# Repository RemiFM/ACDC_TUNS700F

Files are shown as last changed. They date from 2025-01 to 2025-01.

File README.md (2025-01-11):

# 700W 28V AC-DC Module
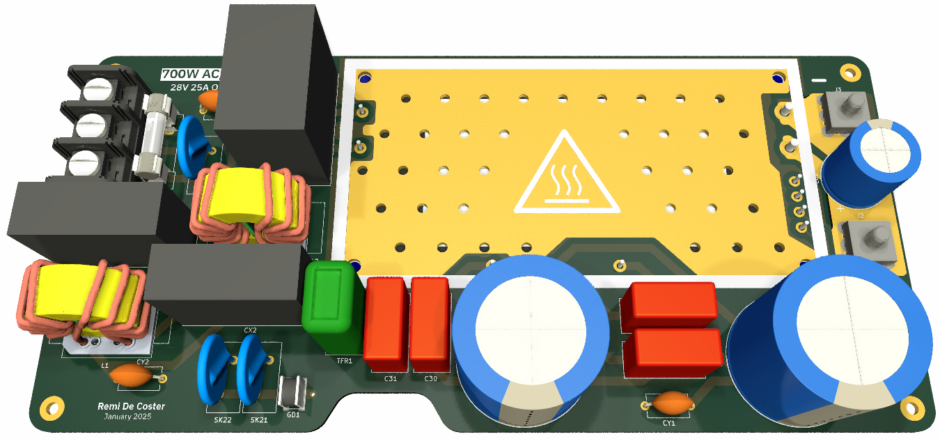
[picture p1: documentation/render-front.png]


PCB carrier board for the Cosel TUNS700F28 AC/DC converter with 28V 25A output. The board can also be used for the TUNS700F12 and TUNS700F48 modules by swapping certain components.
The board is desgined using KiCAD 8 and contains all line filtering and safety protections as recommended in the manufacturer design guide.

> [!CAUTION]
> The power converter operates at AC voltages of 230VAC and delivers up to 700W of power. Improper handling can result in serious injury, electric shock, or fire.

## Ordering Components
A [bill of materials (BOM)](BOM.csv) is available for download. The BOM contains Digi-Key part numbers, and is formatted in a way that can be uploaded to the Digi-Key website for effortless ordering.

## Assembly
For assembly, please make use of the provided [schematic](schematic.pdf), available in pdf format.

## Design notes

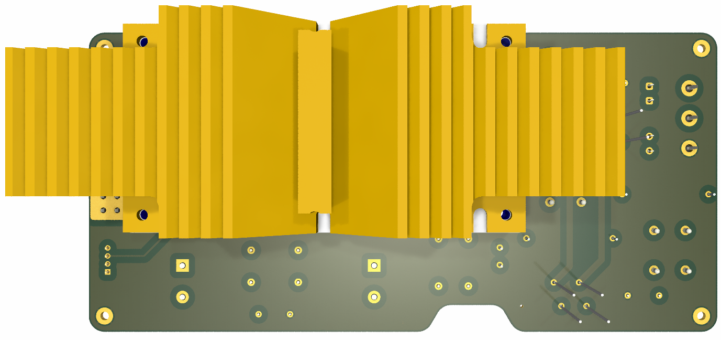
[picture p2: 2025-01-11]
documentation/render-back.png

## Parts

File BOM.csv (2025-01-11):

Reference | Value | Qty | Digi-Key
C11 | 3.3uF | 1 | P123489-ND
C20,C30 | 680nF | 2 | P14204-ND
C21,C31 | 2x680nF | 2 | P14204-ND
C40 | 10uF | 1 | 445-C3216X7R1H106K160AECT-ND
Cbc1,Cbc2 | 2x390uF | 2 | 493-7913-ND
Co1 | 1mF | 1 | 565-2007-ND
CX1,CX2 | 1.5uF | 2 | P15515-ND
CY1,CY2,CY3 | 2.2nF | 3 | 445-174537-ND
F1 | 15A | 1 | F3251-ND + 2 * F4225-ND
GD1 | GDT_2Pin | 1 | 2093-300-SM-RPLFCT-ND
HS1 | ATS1490-ND | 1 | ATS1490-ND
J1 | Screw_Terminal_01x03 | 1 | A98496-ND
J2 | +VO | 1 | 732-74651194RCT-ND
J3 | -VO | 1 | 732-74651194RCT-ND
J4 | Conn_01x04_Pin | 1
L1,L2 | 4.5mH | 2 | 553-3962-ND
R1,R2,R3,R4,R5,R6 | 68k | 6 | 311-68KERCT-ND
SK11,SK21,SK22 | 620V | 3 | 495-5945-ND
TFR1 | 10R 139°C | 1 | 285-1901-ND
U1 | TUNS700F28 | 1 | 1776-1798-ND

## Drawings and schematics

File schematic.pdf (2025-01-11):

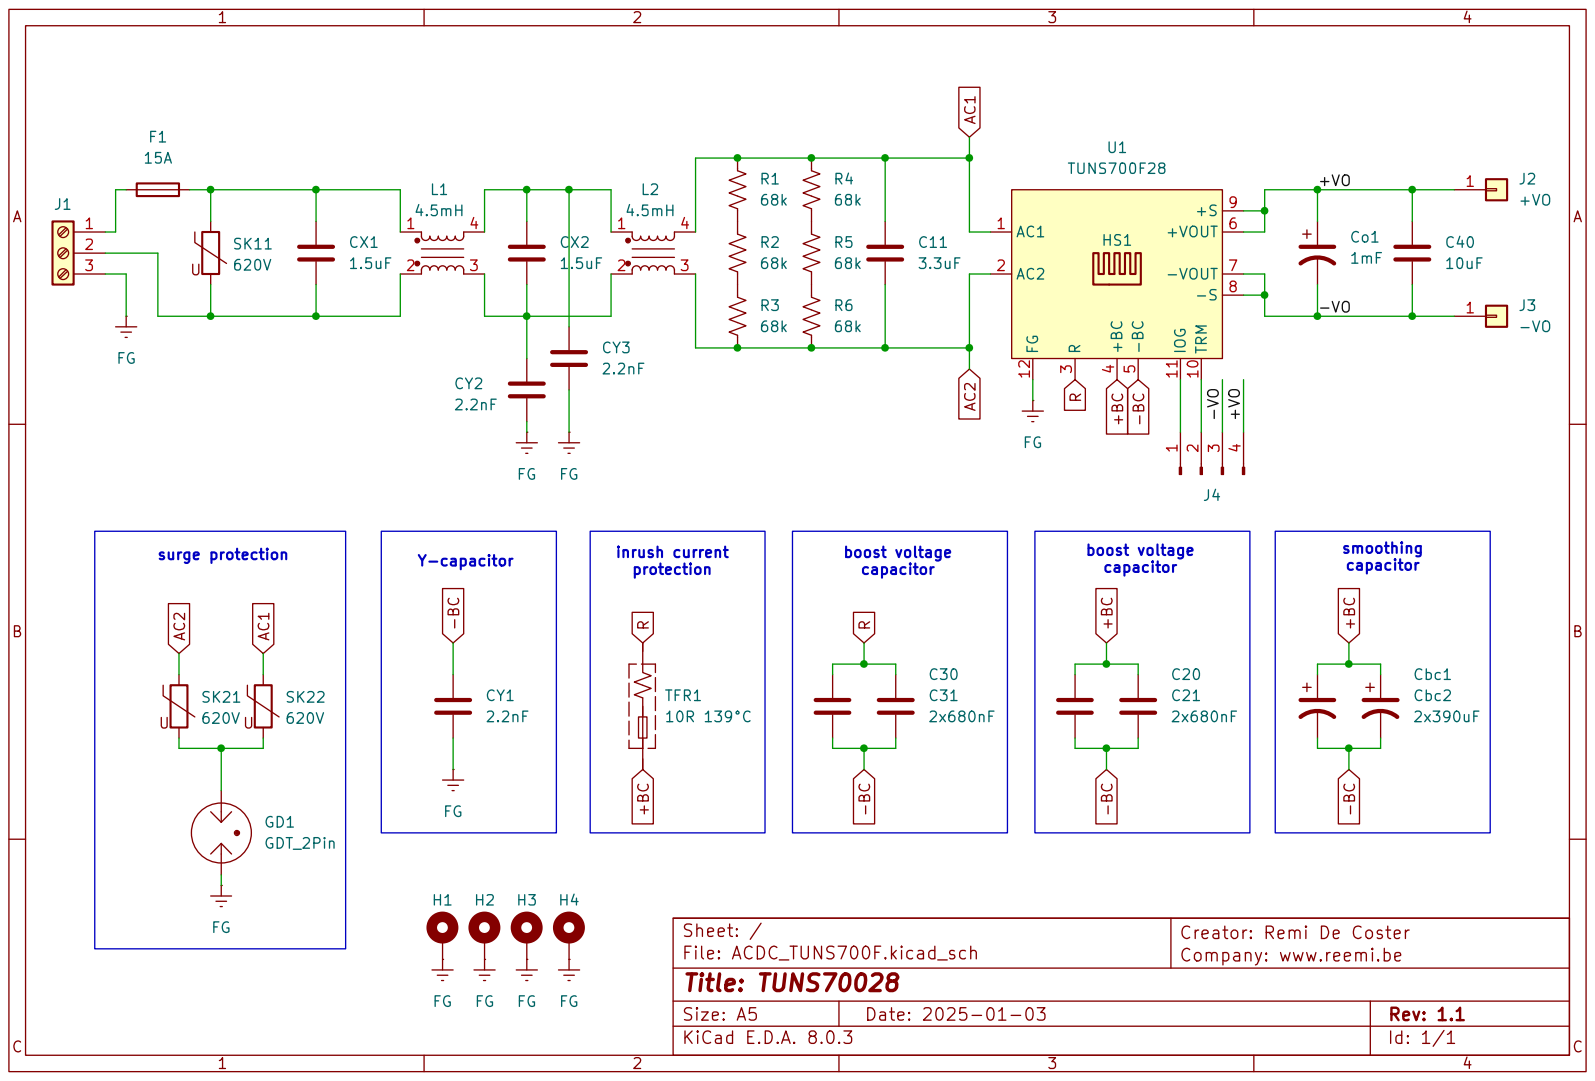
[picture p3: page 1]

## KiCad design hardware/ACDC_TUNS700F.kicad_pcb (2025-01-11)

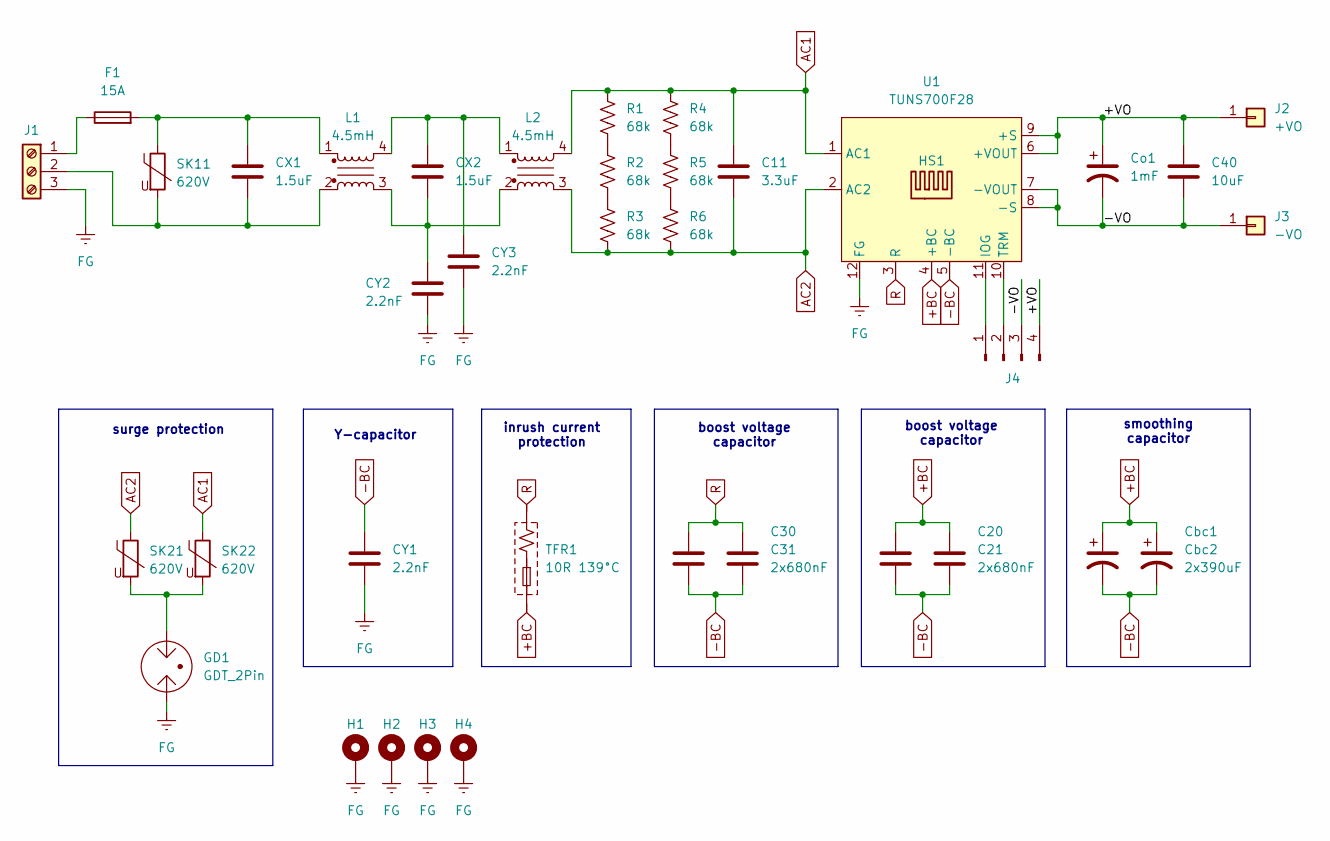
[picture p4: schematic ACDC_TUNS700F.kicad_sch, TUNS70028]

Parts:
C11: 3.3uF; CAP-ECQ-UAAF335K; Digi-Key P123489-ND
C20, C30: 680nF; C_Rect_L18.0mm_W8.0mm_P15.00mm_FKS3_FKP3; Digi-Key P14204-ND
C21, C31: 2x680nF; C_Rect_L18.0mm_W8.0mm_P15.00mm_FKS3_FKP3; Digi-Key P14204-ND
C40: 10uF; C_1206_3216Metric_Pad1.33x1.80mm_HandSolder; Digi-Key 445-C3216X7R1H106K160AECT-ND
CX1, CX2: 1.5uF; CAP-ECQ-UAAF155K; Digi-Key P15515-ND
CY1, CY2, CY3: 2.2nF; C_Disc_D9.0mm_W5.0mm_P10.00mm; Digi-Key 445-174537-ND
Cbc1, Cbc2: 2x390uF; CP_Radial_D30.0mm_P10.00mm_SnapIn; Digi-Key 493-7913-ND
Co1: 1mF; CP_Radial_D16.0mm_P7.50mm; Digi-Key 565-2007-ND
F1: 15A; Fuseholder_Clip-5x20mm_Littelfuse_100_Inline_P20.50x4.60mm_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; Digi-Key F3251-ND + 2 * F4225-ND
GD1: GDT_2Pin; GDT_2093-300-SM-RPLF; Digi-Key 2093-300-SM-RPLFCT-ND
H1, H2, H3, H4: MountingHole_Pad; MountingHole_2.7mm_M2.5_Pad
HS1: ATS1490-ND; Digi-Key ATS1490-ND
J1: Screw_Terminal_01x03; terminal_NC6-P108-03; Digi-Key A98496-ND
J2: +VO; Wuerth_REDCUBE-THR_WP-THRSH_74651194_THR; Digi-Key 732-74651194RCT-ND
J3: -VO; Wuerth_REDCUBE-THR_WP-THRSH_74651194_THR; Digi-Key 732-74651194RCT-ND
J4: Conn_01x04_Pin; PinHeader_1x04_P2.54mm_Vertical
L1, L2: 4.5mH; CMC_PH9455.405NL; Digi-Key 553-3962-ND
R1, R2, R3, R4, R5, R6: 68k; R_1206_3216Metric_Pad1.30x1.75mm_HandSolder; Digi-Key 311-68KERCT-ND
SK11, SK21, SK22: 620V; RV_Disc_D15,5mm_W7,1mm_P7,5mm; Digi-Key 495-5945-ND
TFR1: 10R 139°C; TFR_DFP10112; Digi-Key 285-1901-ND
U1: TUNS700F28; Digi-Key 1776-1798-ND

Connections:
+BC: C20.1, C21.1, Cbc1.1, Cbc2.1, TFR1.2, U1.4 (+BC)
-BC: C20.2, C21.2, C30.2, C31.2, CY1.1, Cbc1.2, Cbc2.2, U1.5 (-BC)
/+VO: C40.1, Co1.1, J2.1, J4.4, U1.6 (+VOUT), U1.9 (+S)
/-VO: C40.2, Co1.2, J3.1, J4.3, U1.7 (-VOUT), U1.8 (-S)
AC1: C11.1, L2.4, R1.1, R4.1, SK22.1, U1.1 (AC1)
AC2: C11.2, L2.3, R3.2, R6.2, SK21.1, U1.2 (AC2)
FG: CY1.2, CY2.2, CY3.2, GD1.1, H1.1, H2.1, H3.1, H4.1, J1.3, U1.12 (FG)
unnamed: CX1.1, F1.2, L1.1, SK11.1
unnamed: CX2.1, CY3.1, L1.4, L2.1
unnamed: CX2.2, CY2.1, L1.3, L2.2
unnamed: GD1.3, SK21.2, SK22.2
unnamed: F1.1, J1.1
unnamed: CX1.2, J1.2, L1.2, SK11.2
unnamed: J4.1, U1.11 (IOG)
unnamed: J4.2, U1.10 (TRM)
unnamed: R1.2, R2.1
unnamed: R2.2, R3.1
unnamed: R4.2, R5.1
unnamed: R5.2, R6.1
R: C30.1, C31.1, TFR1.1, U1.3 (R)

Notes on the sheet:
Y-capacitor
surge protection
boost voltage capacitor
smoothing capacitor
inrush current protection

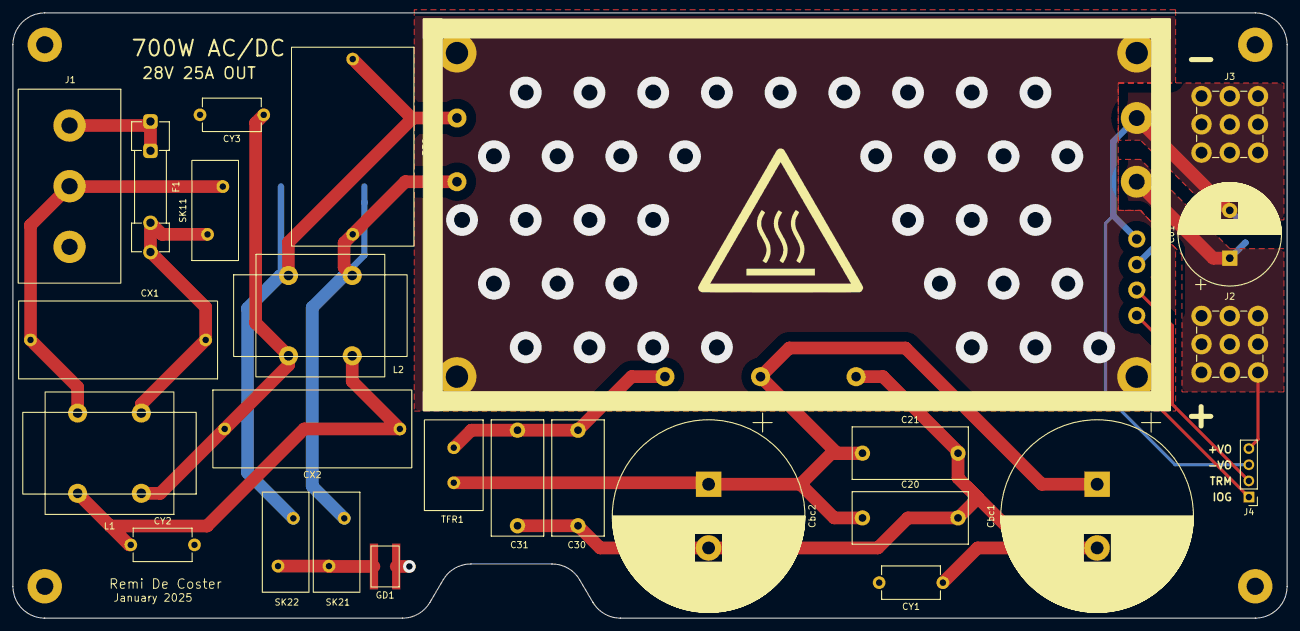
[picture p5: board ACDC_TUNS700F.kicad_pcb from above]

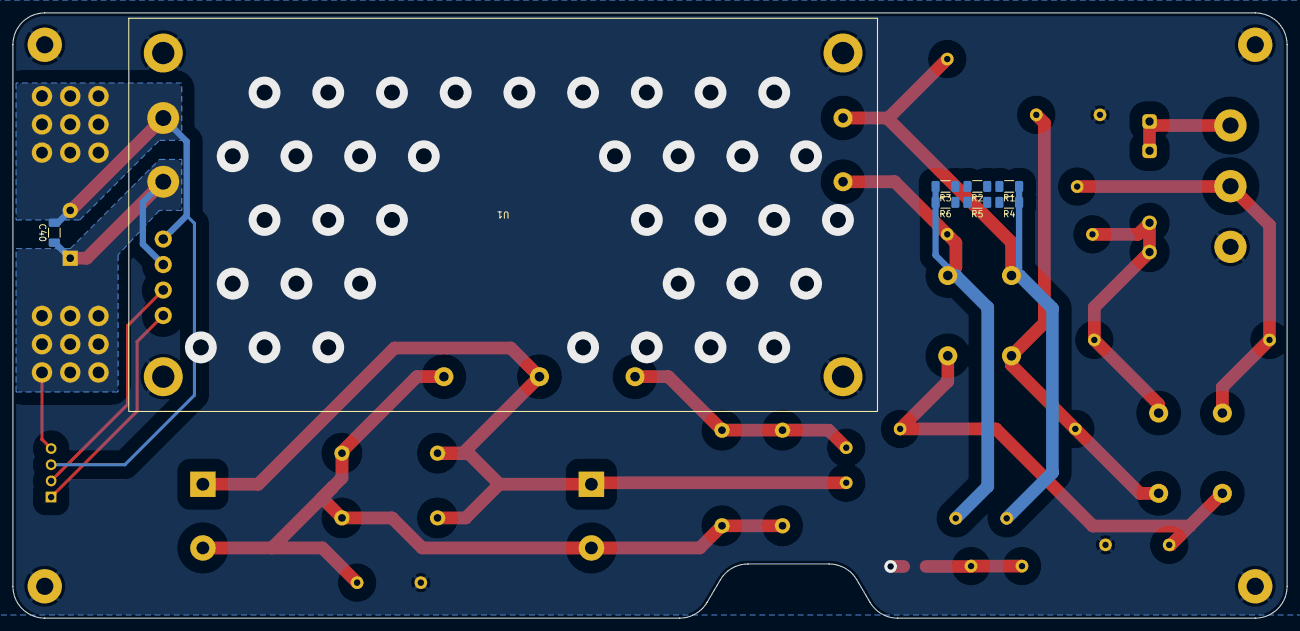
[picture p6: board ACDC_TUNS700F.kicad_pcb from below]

Board: 2 copper layers, 200.0 x 95.0 mm, 37 parts (8 on the bottom side), 20 nets.

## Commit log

2025-01-03 footprint creation
    [ACDC_TUNS700F.kicad_pcb, ACDC_TUNS700F.kicad_sch]
2025-01-03 input ac filter
    [ACDC_TUNS700F.kicad_pcb, ACDC_TUNS700F.kicad_sch]
2025-01-07 reference schematic complete
    [ACDC_TUNS700F.kicad_pcb, ACDC_TUNS700F.kicad_sch]
2025-01-11 board layout updates
    [ACDC_TUNS700F.kicad_pcb, ACDC_TUNS700F.kicad_sch]
2025-01-11 PCB renders
2025-01-11 Bill of materials
    [BOM.csv]
2025-01-11 media uploads
    [ACDC_TUNS700F.kicad_pcb]
2025-01-11 silkscreen details
    [ACDC_TUNS700F.kicad_pcb]
